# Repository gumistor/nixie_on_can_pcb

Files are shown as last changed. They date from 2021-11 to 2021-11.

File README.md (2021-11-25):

# nixie_on_can_pcb
Six NIXIE display with CAN bus interface. Powered with step up regulator.

Main controler: PIC18F2480
CAN transciever: MCP2551

PIC utylize PWM output to drive step-up regulator. 
Step-up regulator provides high voltage to lamps (over 100V!!). 
PIC uses multiplexing to light up digits.

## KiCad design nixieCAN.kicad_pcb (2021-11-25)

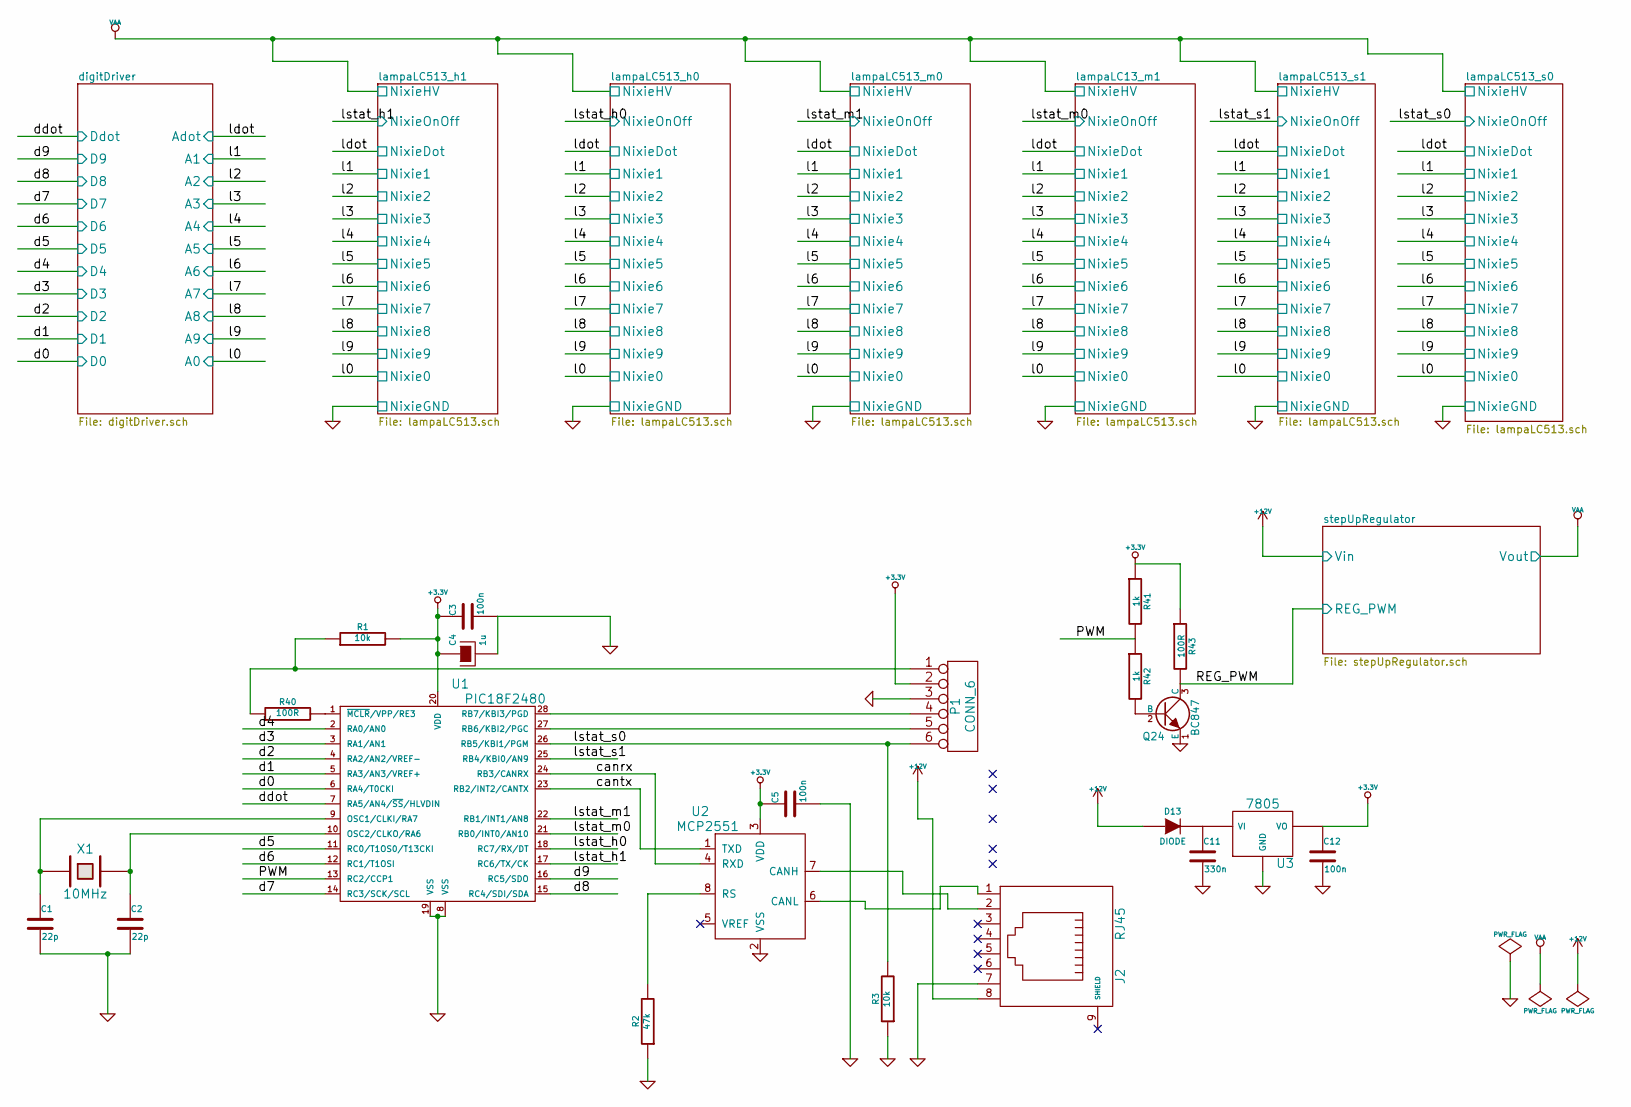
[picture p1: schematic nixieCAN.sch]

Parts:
C1, C2: 22p
C3, C5, C12: 100n
C4: 1u
C11: 330n
D13: DIODE
J2: RJ45
P1: CONN_6
Q24: BC847
R1, R3: 10k
R2: 47k
R40, R43: 100R
R41, R42: 1k
U1: PIC18F2480
U2: MCP2551
U3: 7805
X1: 10MHz

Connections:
+3.3V: C3.1, C4.1, C5.1, C12.1, P1.2, R1.2, R41.1, R43.1, U1.20 (VDD), U2.3 (VDD), U3.3 (VO)
+12V: D13.1 (A), J2.8; also elsewhere on the board
/PWM: R41.2, R42.1, U1.13 (RC2/CCP1)
/canrx: U1.24 (RB3/CANRX), U2.4 (RXD)
/cantx: U1.23 (RB2/INT2/CANTX), U2.1 (TXD)
/digitDriver/D0: U1.6 (RA4/T0CKI); also elsewhere on the board
/digitDriver/D1: U1.5 (RA3/AN3/VREF+); also elsewhere on the board
/digitDriver/D2: U1.4 (RA2/AN2/VREF-); also elsewhere on the board
/digitDriver/D3: U1.3 (RA1/AN1); also elsewhere on the board
/digitDriver/D4: U1.2 (RA0/AN0); also elsewhere on the board
/digitDriver/D5: U1.11 (RC0/T1OS0/T13CKI); also elsewhere on the board
/digitDriver/D6: U1.12 (RC1/T1OSI); also elsewhere on the board
/digitDriver/D7: U1.14 (RC3/SCK/SCL); also elsewhere on the board
/digitDriver/D8: U1.15 (RC4/SDI/SDA); also elsewhere on the board
/digitDriver/D9: U1.16 (RC5/SDO); also elsewhere on the board
/digitDriver/Ddot: U1.7 (RA5/AN4/~SS~/HLVDIN); also elsewhere on the board
/lampaLC13_m1/NixieOnOff: U1.21 (RB0/INT0/AN10); also elsewhere on the board
/lampaLC513_h0/NixieOnOff: U1.18 (RC7/RX/DT); also elsewhere on the board
/lampaLC513_h1/NixieOnOff: U1.17 (RC6/TX/CK); also elsewhere on the board
/lampaLC513_m0/NixieOnOff: U1.22 (RB1/INT1/AN8); also elsewhere on the board
/lampaLC513_s0/NixieOnOff: P1.6, R3.2, U1.26 (RB5/KBI1/PGM); also elsewhere on the board
/lampaLC513_s1/NixieOnOff: U1.25 (RB4/KBI0/AN9); also elsewhere on the board
/stepUpRegulator/REG_PWM: Q24.3 (C), R43.2; also elsewhere on the board
GND: C1.2, C2.2, C3.2, C4.2, C5.2, C11.2, C12.2, J2.7, P1.3, Q24.1 (E), R2.1, R3.1, U1.8 (VSS), U1.19 (VSS), U2.2 (VSS), U3.2 (GND); also elsewhere on the board
unnamed: P1.5, U1.27 (RB6/KBI2/PGC)
unnamed: R2.2, U2.8 (RS)
unnamed: J2.1, U2.6 (CANL)
unnamed: C11.1, D13.2 (K), U3.1 (VI)
unnamed: J2.2, U2.7 (CANH)
unnamed: Q24.2 (B), R42.2
unnamed: P1.4, U1.28 (RB7/KBI3/PGD)
unnamed: P1.1, R1.1, R40.1
unnamed: R40.2, U1.1 (~MCLR~/VPP/RE3)
unnamed: C1.1, U1.9 (OSC1/CLKI/RA7), X1.1
unnamed: C2.1, U1.10 (OSC2/CLKO/RA6), X1.2

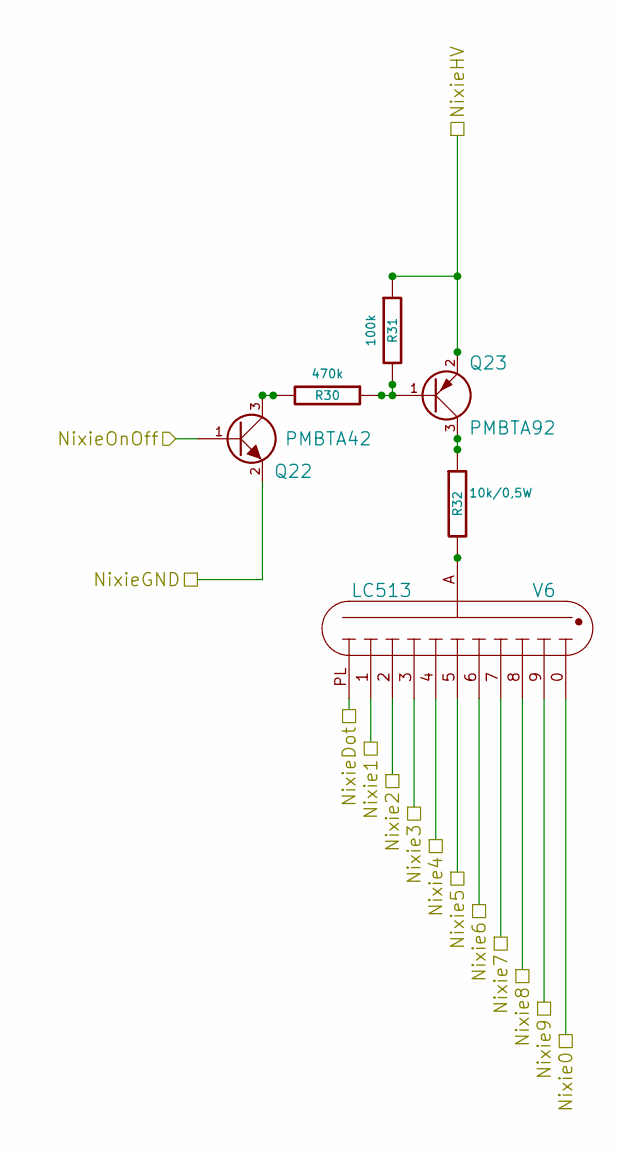
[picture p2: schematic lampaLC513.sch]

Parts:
Q1: PMBTA42; SOT23
Q2: PMBTA92; SOT23
R4: 470k
R5: 100k
R6: 10k/0,5W
V1: LC513

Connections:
/digitDriver/A0: V1.0; also elsewhere on the board
/digitDriver/A1: V1.1; also elsewhere on the board
/digitDriver/A2: V1.2; also elsewhere on the board
/digitDriver/A3: V1.3; also elsewhere on the board
/digitDriver/A4: V1.4; also elsewhere on the board
/digitDriver/A5: V1.5; also elsewhere on the board
/digitDriver/A6: V1.6; also elsewhere on the board
/digitDriver/A7: V1.7; also elsewhere on the board
/digitDriver/A8: V1.8; also elsewhere on the board
/digitDriver/A9: V1.9; also elsewhere on the board
/digitDriver/Adot: V1.PL; also elsewhere on the board
/lampaLC513_s0/NixieOnOff: Q1.1 (B); also elsewhere on the board
GND: Q1.2 (E); also elsewhere on the board
unnamed: R6.2, V1.A
unnamed: Q2.3 (C), R6.1
unnamed: Q2.1 (B), R4.1, R5.2
unnamed: Q1.3 (C), R4.2
VAA: Q2.2 (E), R5.1; also elsewhere on the board

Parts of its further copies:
Q3, Q16, Q18, Q20, Q22: PMBTA42; SOT23
Q4, Q17, Q19, Q21, Q23: PMBTA92; SOT23
R7, R21, R24, R27, R30: 470k
R8, R22, R25, R28, R31: 100k
R9, R23, R26, R29, R32: 10k/0,5W
V2, V3, V4, V5, V6: LC513

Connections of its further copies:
/digitDriver/A0: V2.0, V3.0, V4.0, V5.0, V6.0; also elsewhere on the board
/digitDriver/A1: V2.1, V3.1, V4.1, V5.1, V6.1; also elsewhere on the board
/digitDriver/A2: V2.2, V3.2, V4.2, V5.2, V6.2; also elsewhere on the board
/digitDriver/A3: V2.3, V3.3, V4.3, V5.3, V6.3; also elsewhere on the board
/digitDriver/A4: V2.4, V3.4, V4.4, V5.4, V6.4; also elsewhere on the board
/digitDriver/A5: V2.5, V3.5, V4.5, V5.5, V6.5; also elsewhere on the board
/digitDriver/A6: V2.6, V3.6, V4.6, V5.6, V6.6; also elsewhere on the board
/digitDriver/A7: V2.7, V3.7, V4.7, V5.7, V6.7; also elsewhere on the board
/digitDriver/A8: V2.8, V3.8, V4.8, V5.8, V6.8; also elsewhere on the board
/digitDriver/A9: V2.9, V3.9, V4.9, V5.9, V6.9; also elsewhere on the board
/digitDriver/Adot: V2.PL, V3.PL, V4.PL, V5.PL, V6.PL; also elsewhere on the board
/lampaLC13_m1/NixieOnOff: Q18.1 (B); also elsewhere on the board
/lampaLC513_h0/NixieOnOff: Q20.1 (B); also elsewhere on the board
/lampaLC513_h1/NixieOnOff: Q22.1 (B); also elsewhere on the board
/lampaLC513_m0/NixieOnOff: Q16.1 (B); also elsewhere on the board
/lampaLC513_s1/NixieOnOff: Q3.1 (B); also elsewhere on the board
GND: Q3.2 (E), Q16.2 (E), Q18.2 (E), Q20.2 (E), Q22.2 (E); also elsewhere on the board
unnamed: R9.2, V2.A
unnamed: Q4.1 (B), R7.1, R8.2
unnamed: Q4.3 (C), R9.1
unnamed: Q3.3 (C), R7.2
unnamed: R23.2, V3.A
unnamed: Q17.3 (C), R23.1
unnamed: Q17.1 (B), R21.1, R22.2
unnamed: Q16.3 (C), R21.2
unnamed: Q19.1 (B), R24.1, R25.2
unnamed: Q18.3 (C), R24.2
unnamed: R26.2, V4.A
unnamed: Q19.3 (C), R26.1
unnamed: Q20.3 (C), R27.2
unnamed: Q21.1 (B), R27.1, R28.2
unnamed: R29.2, V5.A
unnamed: Q21.3 (C), R29.1
unnamed: Q22.3 (C), R30.2
unnamed: Q23.1 (B), R30.1, R31.2
unnamed: R32.2, V6.A
unnamed: Q23.3 (C), R32.1
VAA: Q4.2 (E), Q17.2 (E), Q19.2 (E), Q21.2 (E), Q23.2 (E), R8.1, R22.1, R25.1, R28.1, R31.1; also elsewhere on the board

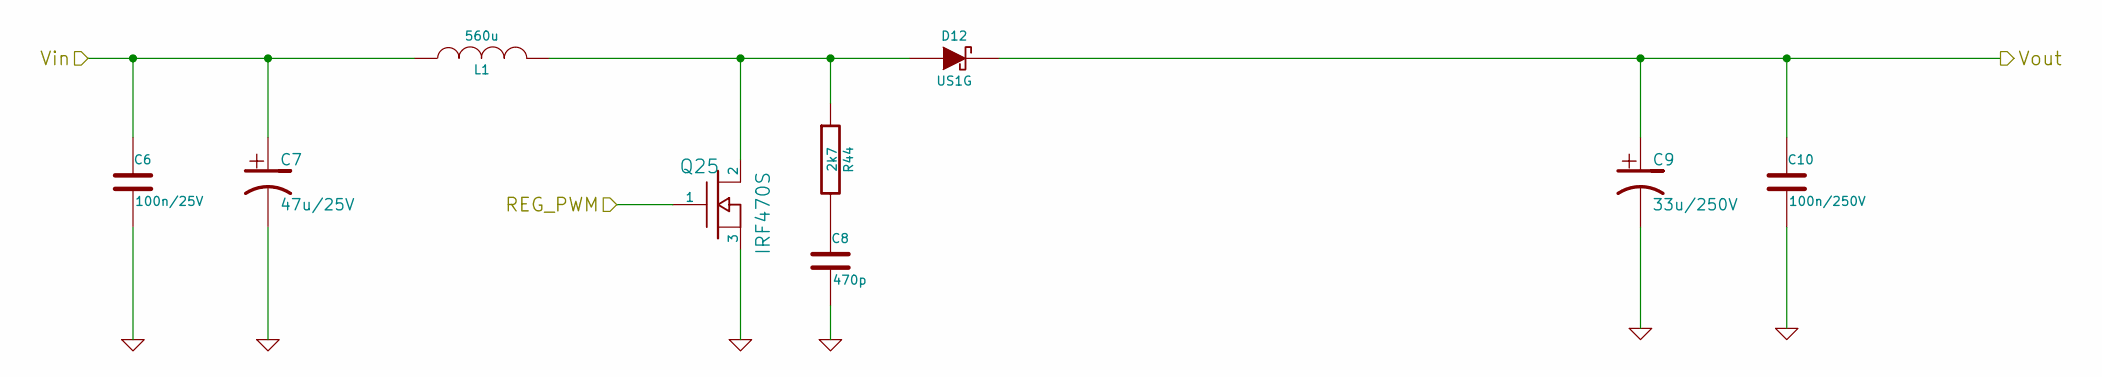
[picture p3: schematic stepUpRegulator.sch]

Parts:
C6: 100n/25V
C7: 47u/25V
C8: 470p
C9: 33u/250V
C10: 100n/250V
D12: US1G
L1: 560u
Q25: IRF470S
R44: 2k7

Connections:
+12V: C6.1, C7.1, L1.1; also elsewhere on the board
/stepUpRegulator/REG_PWM: Q25.1; also elsewhere on the board
GND: C6.2, C7.2, C8.2, C9.2, C10.2, Q25.3; also elsewhere on the board
unnamed: C8.1, R44.2
unnamed: D12.1 (A), L1.2, Q25.2, R44.1
VAA: C9.1, C10.1, D12.2 (K); also elsewhere on the board

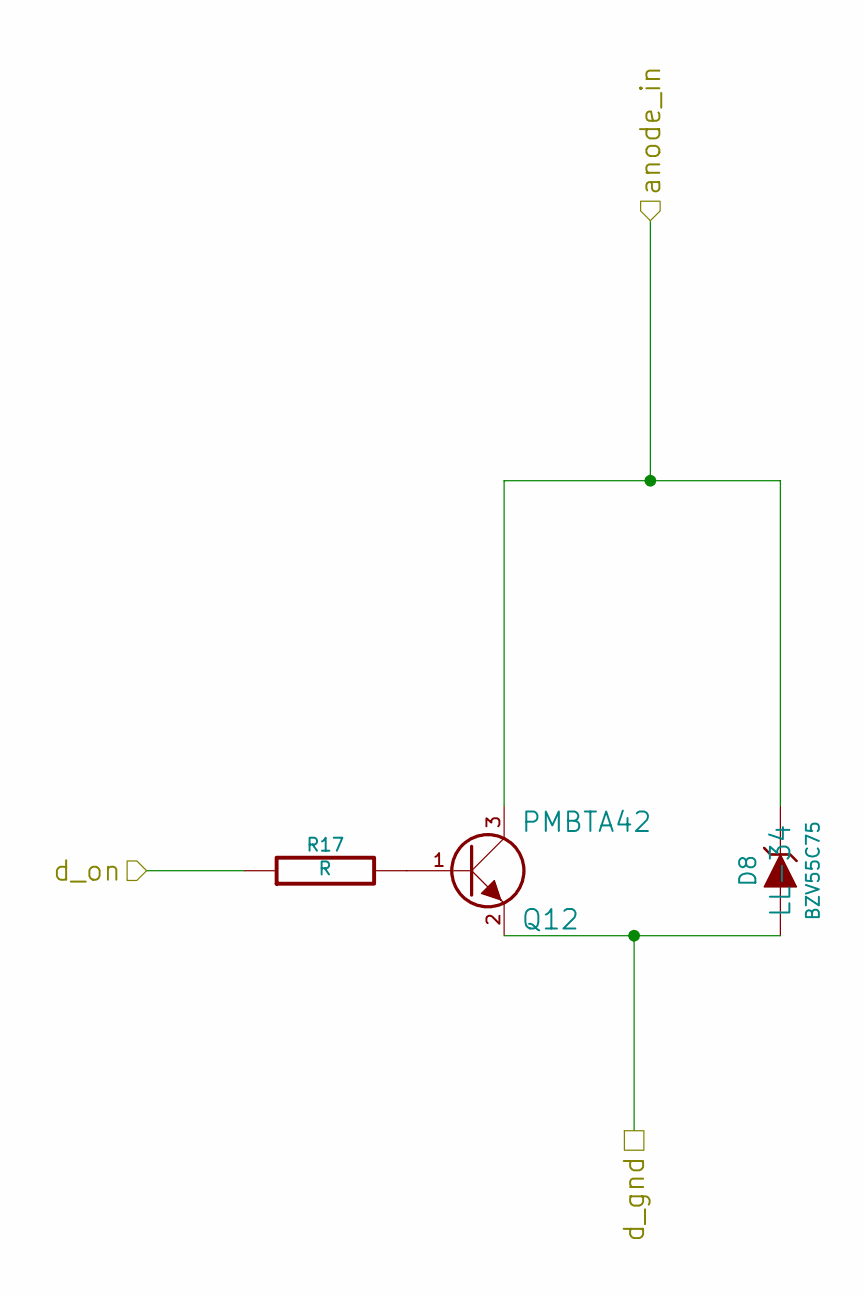
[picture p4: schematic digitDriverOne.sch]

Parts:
D1: BZV55C75; LL-34
Q5: PMBTA42; SOT23
R10: R

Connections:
/digitDriver/Adot: D1.2 (K), Q5.3 (C); also elsewhere on the board
/digitDriver/Ddot: R10.1; also elsewhere on the board
GND: D1.1 (A), Q5.2 (E); also elsewhere on the board
unnamed: Q5.1 (B), R10.2

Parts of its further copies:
D2, D3, D4, D5, D6, D7, D8, D9, D10, D11: BZV55C75; LL-34
Q6, Q7, Q8, Q9, Q10, Q11, Q12, Q13, Q14, Q15: PMBTA42; SOT23
R11, R12, R13, R14, R15, R16, R17, R18, R19, R20: R

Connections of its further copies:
/digitDriver/A0: D11.2 (K), Q15.3 (C); also elsewhere on the board
/digitDriver/A1: D2.2 (K), Q6.3 (C); also elsewhere on the board
/digitDriver/A2: D3.2 (K), Q7.3 (C); also elsewhere on the board
/digitDriver/A3: D4.2 (K), Q8.3 (C); also elsewhere on the board
/digitDriver/A4: D5.2 (K), Q9.3 (C); also elsewhere on the board
/digitDriver/A5: D6.2 (K), Q10.3 (C); also elsewhere on the board
/digitDriver/A6: D7.2 (K), Q11.3 (C); also elsewhere on the board
/digitDriver/A7: D8.2 (K), Q12.3 (C); also elsewhere on the board
/digitDriver/A8: D9.2 (K), Q13.3 (C); also elsewhere on the board
/digitDriver/A9: D10.2 (K), Q14.3 (C); also elsewhere on the board
/digitDriver/D0: R20.1; also elsewhere on the board
/digitDriver/D1: R19.1; also elsewhere on the board
/digitDriver/D2: R18.1; also elsewhere on the board
/digitDriver/D3: R17.1; also elsewhere on the board
/digitDriver/D4: R16.1; also elsewhere on the board
/digitDriver/D5: R15.1; also elsewhere on the board
/digitDriver/D6: R14.1; also elsewhere on the board
/digitDriver/D7: R13.1; also elsewhere on the board
/digitDriver/D8: R12.1; also elsewhere on the board
/digitDriver/D9: R11.1; also elsewhere on the board
GND: D2.1 (A), D3.1 (A), D4.1 (A), D5.1 (A), D6.1 (A), D7.1 (A), D8.1 (A), D9.1 (A), D10.1 (A), D11.1 (A), Q6.2 (E), Q7.2 (E), Q8.2 (E), Q9.2 (E), Q10.2 (E), Q11.2 (E), Q12.2 (E), Q13.2 (E), Q14.2 (E), Q15.2 (E); also elsewhere on the board
unnamed: Q6.1 (B), R11.2
unnamed: Q7.1 (B), R12.2
unnamed: Q8.1 (B), R13.2
unnamed: Q9.1 (B), R14.2
unnamed: Q10.1 (B), R15.2
unnamed: Q11.1 (B), R16.2
unnamed: Q12.1 (B), R17.2
unnamed: Q13.1 (B), R18.2
unnamed: Q14.1 (B), R19.2
unnamed: Q15.1 (B), R20.2

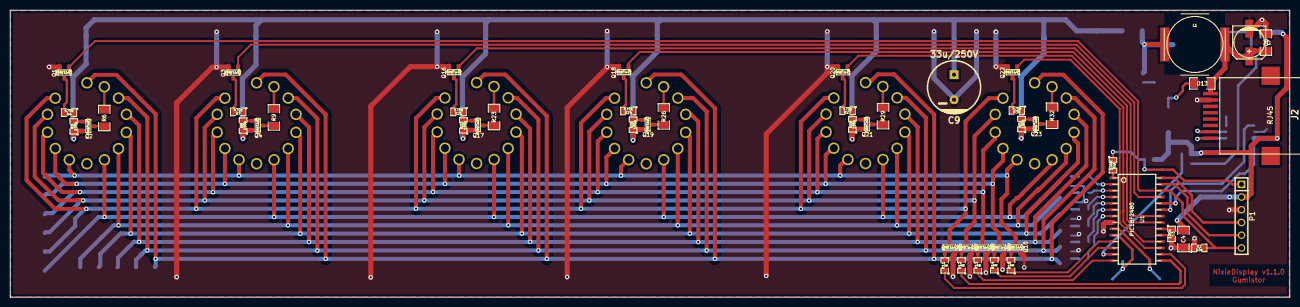
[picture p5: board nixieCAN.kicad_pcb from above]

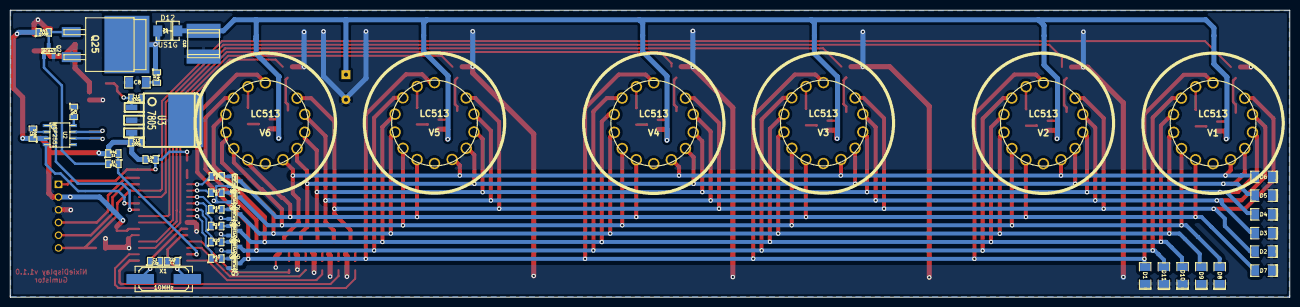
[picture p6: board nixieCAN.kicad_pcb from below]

Board: 2 copper layers, 255.3 x 57.2 mm, 100 parts (48 on the bottom side), 84 nets.
